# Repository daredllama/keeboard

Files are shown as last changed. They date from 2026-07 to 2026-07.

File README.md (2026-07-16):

# Keeboard



A custom 75%-layout mechanical keyboard, with per-key backlighting, a rotary encoder, a OLED status display, and RMK (Rust) firmware on an RP2040 (Raspberry Pi Pico).

---

## Features

- **79-keys** (78 keys + integrated rotary encoder pushbutton)
- **Per-key backlighting** — SK6812 Mini LEDs, one per switch
- **Rotary encoder** (EC11) — rotation bound to volume, click bound to OLED toggle
- **128×64 I2C OLED** - status display 
- **RMK firmware** (Rust) running on RP2040
- **Sandwich mount** case, plate-mount stabilizers, Cherry MX-compatible switches

---

## Hardware

| Component | Spec |
|---|---|
| MCU | Raspberry Pi Pico (RP2040) |
| Switches | Cherry MX-compatible |
| LEDs | SK6812 Mini, ~79x, per-key |
| Diodes | 1N4148WS (SOD-323) |
| Decoupling caps | 100nF ceramic, 0402 |
| Encoder | EC11 |
| Display | 128×64 I2C OLED (0.96") |
| Stabilizers | Cherry-style plate-mount — 2u (Backspace, Enter, LShift), 6.25u (Spacebar) |

## Plate / Case

- Case screws: M3



## Pin Mapping (RP2040 / Pico)

| Function | GPIO |
|---|---|
| Columns (col0–col14) | GPIO0, 9, 7, 12, 13, 3, 14, 20, 17, 6, 16, 5, 4, 2, 21 |
| Rows (row0–row5) | GPIO15, 11, 10, 8, 1, 22 |
| Encoder A / B | GPIO18 / GPIO19 |
| LED data | GPIO26 |
| OLED SDA / SCL | GPIO27 / GPIO28 |











## Firmware

**Flashing:**
1. Hold the Pico's BOOTSEL button while plugging it in via USB
2. `cargo run --release`
   (uses `elf2uf2-rs` by default — install once with `cargo install elf2uf2-rs`)

**Keymap:** defined in `keyboard.toml` under `[layout].keymap`. 3 layers:
- **Layer 0** — base QWERTY layout matching the F75 layout
- **Layer 1** — Fn layer, RGB controls (mode/brightness on arrow keys)
- **Layer 2** — reserved

## PCB / Assembly Notes

- LEDs are intended to be **reverse-mounted** (bottom side, shining through a PCB cutout) — assembled and soldered by hand, **not** included in the JLCPCB assembly BOM/CPL

## Reflection

For this build, I really challenged myself with tedious ahh work. Even though that making this board was quite tedious, it was a good learning experience,
espcially since this is my first-ever keyboard. I wanted to add a OLED screen so that I could have cool animations or somthing moving on the keyboard while 
I typed. I learned many things form this project, such as how tedious it is to put per-key LEDS for every key. That might have been a mistake. But, I also
learned how to edit/make footprints.

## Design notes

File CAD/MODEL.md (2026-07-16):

## To view the Onshape Doc of this project:

[https://cad.onshape.com/documents/a453df504ee4fbe3ddf03851/w/f0b62b2b0d6551e8bc1848da/e/73e8cfd1b225c73540e4d9f0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](url)

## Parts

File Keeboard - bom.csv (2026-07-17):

Part | Link | Quantity | Cost | Notes
Raspberry Pi Pico | https://www.mouser.com/en/ProductDetail/Raspberry-Pi/SC0915?qs=T%252BzbugeAwjgnLi4azxXVFA%3D%3D&mgh=1 | 1 | $4
0402 100nF Cap | https://jlcpcb.com/partdetail/1877-CL05B104KO5NNNC/C1525 | 79 |  | 0.42 (With PCB)
SOD 323 1n4148 | https://jlcpcb.com/partdetail/2485-1N4148WS/C2128 | 79 |  | 1.08 (With PCB)
0.96" OLED Screen | https://www.aliexpress.us/item/3256805954920554.html?curPageLogUid=JNbJdGII2aV6 | 1 | $0.99
SK6812 MINI-E LED | https://www.lcsc.com/product-detail/C5149201.html?s_z=n_SK6812%2520MINI-E | 79 |  | 5.55 (With PCB)
0402 500 Resistor | https://jlcpcb.com/partdetail/YAGEO-RT0402FRE07500RL/C6460545 | 1 |  | 0.01 (With PCB)
MX 2u Stab | https://www.aliexpress.us/item/2251832678467969.html?src=google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 | 3 | $2.97
MX 6.25u Stab | https://www.aliexpress.us/item/2251832678467969.html?src=google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 | 1 | $0.99
Cherry MX Switch | https://www.aliexpress.us/item/3256802192387196.html?gatewayAdapt=glo2usa4itemAdapt | 78 | $11.53
EC_11 Rotary Encoder (Plum 15mm) | https://jlcpcb.com/parts/componentSearch?searchTxt=ec11%20rotary%20encoder | 1 | $2.12
DSA Keycap 1u | https://www.aliexpress.us/item/3256812054128259.html?src=google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 | 67 | $13.20 | All keycaps in set
DSA Keycap 1.25u |  | 3
DSA Keycap 1.5u |  | 2
DSA Keycap 1.75u |  | 2
DSA Keycap 2u |  | 1
DSA Keycap 2.25 u |  | 2
DSA Keycap 6.25u |  | 1
PCB |  | 2 assembled +3 blank | $82.26
 |  | Total | $118

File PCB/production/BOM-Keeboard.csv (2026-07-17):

Comment | Designator | Footprint | LCSC | Quantity
100nF | C1,C10,C11,C12,C13,C14,C15,C16,C17,C18,C19,C2,C20,C21,C22,C23,C24,C25,C26,C27,C28,C29,C3,C30,C31,C32,C33,C34,C35,C36,C37,C38,C39,C4,C40,C41,C42,C43,C44,C45,C46,C47,C48,C49,C5,C50,C51,C52,C53,C54,C55,C56,C57,C58,C59,C6,C60,C61,C62,C63,C64,C65,C66,C67,C68,C69,C7,C70,C71,C72,C73,C74,C75,C76,C77,C78,C79,C8,C9 | C_0402_1005Metric | C1525 | 79
500 | R1 | R_0402_1005Metric | C6460545 | 1
Diode | D1,D10,D11,D12,D13,D14,D15,D16,D17,D18,D19,D2,D20,D21,D22,D23,D24,D25,D26,D27,D28,D29,D3,D30,D31,D32,D33,D34,D35,D36,D37,D38,D39,D4,D40,D41,D42,D43,D44,D45,D46,D47,D48,D49,D5,D50,D51,D52,D53,D54,D55,D56,D57,D58,D59,D6,D60,D61,D62,D63,D64,D65,D66,D67,D68,D69,D7,D70,D71,D72,D73,D74,D75,D76,D77,D78,D79,D8,D9 | D_SOD-323 | C2128 | 79
SK6812MINI | LED1,LED10,LED11,LED12,LED13,LED14,LED15,LED16,LED17,LED18,LED19,LED2,LED20,LED21,LED22,LED23,LED24,LED25,LED26,LED27,LED28,LED29,LED3,LED30,LED31,LED32,LED33,LED34,LED35,LED36,LED37,LED38,LED39,LED4,LED40,LED41,LED42,LED43,LED44,LED45,LED46,LED47,LED48,LED49,LED5,LED50,LED51,LED52,LED53,LED54,LED55,LED56,LED57,LED58,LED59,LED6,LED60,LED61,LED62,LED63,LED64,LED65,LED66,LED67,LED68,LED69,LED7,LED70,LED71,LED72,LED73,LED74,LED75,LED76,LED77,LED78,LED79,LED8,LED9 | LED_SK6812MINI_PLCC4_3.5x3.5mm_Correct | C5149201 | 79

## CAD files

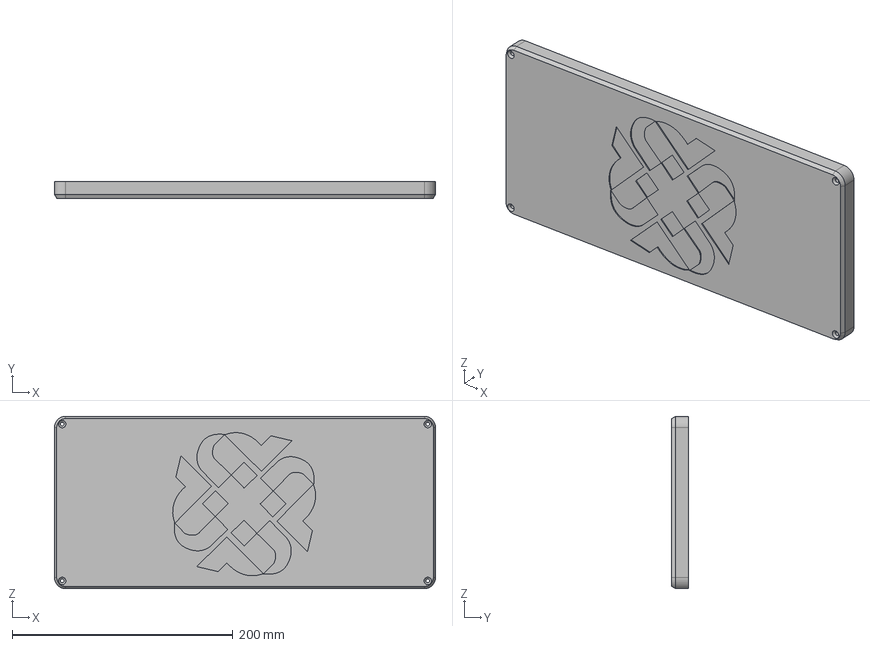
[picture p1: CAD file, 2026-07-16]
CAD/case bottom.step
345.0 x 15.0 x 156.0 mm

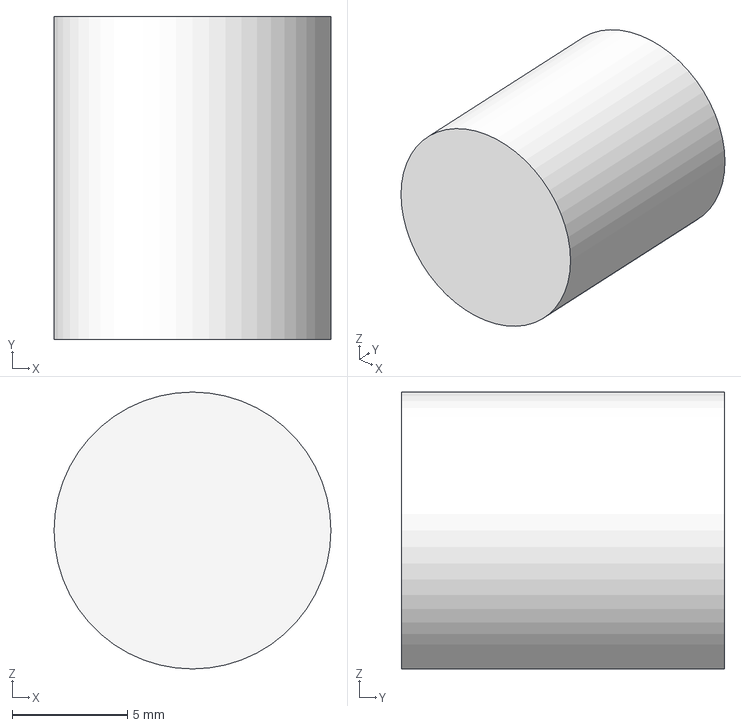
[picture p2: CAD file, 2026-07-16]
CAD/knob.step
12.0 x 14.0 x 12.0 mm

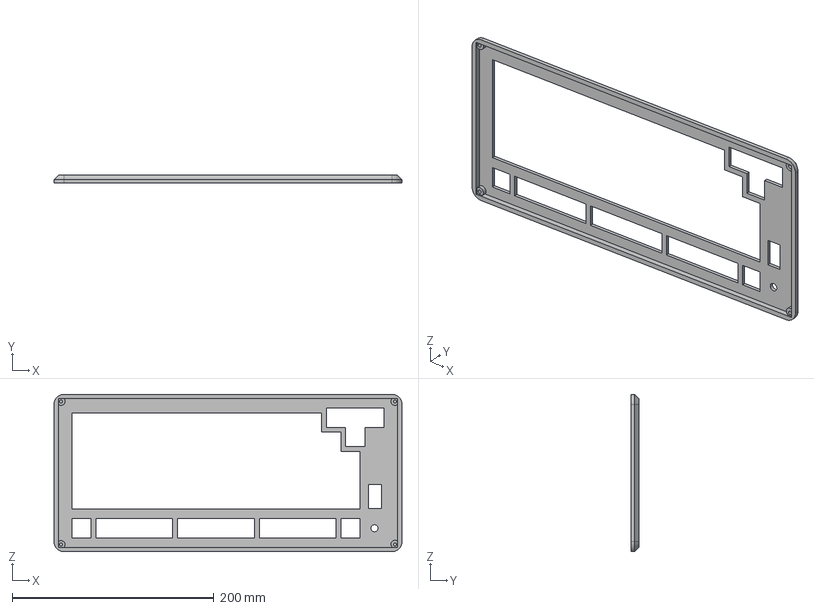
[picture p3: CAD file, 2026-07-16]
CAD/plate.step
345.0 x 8.00 x 156.0 mm

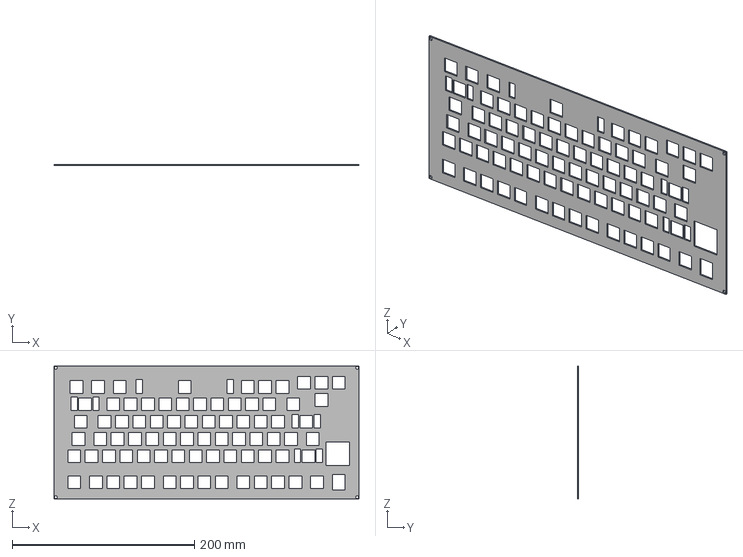
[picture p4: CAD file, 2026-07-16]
CAD/case top.step
335.0 x 1.50 x 146.0 mm

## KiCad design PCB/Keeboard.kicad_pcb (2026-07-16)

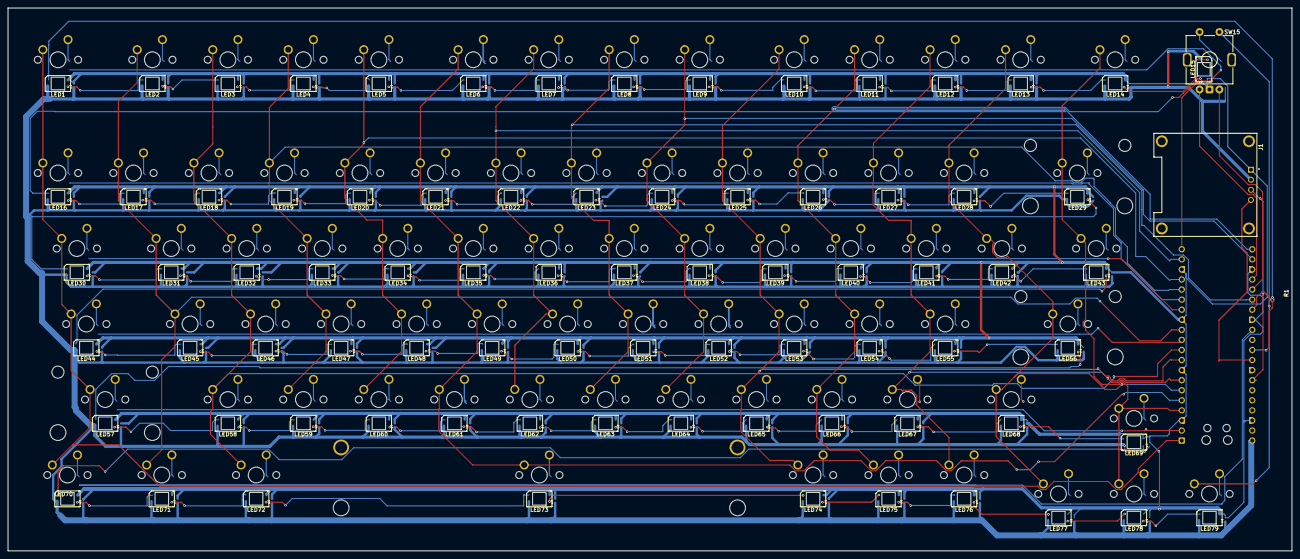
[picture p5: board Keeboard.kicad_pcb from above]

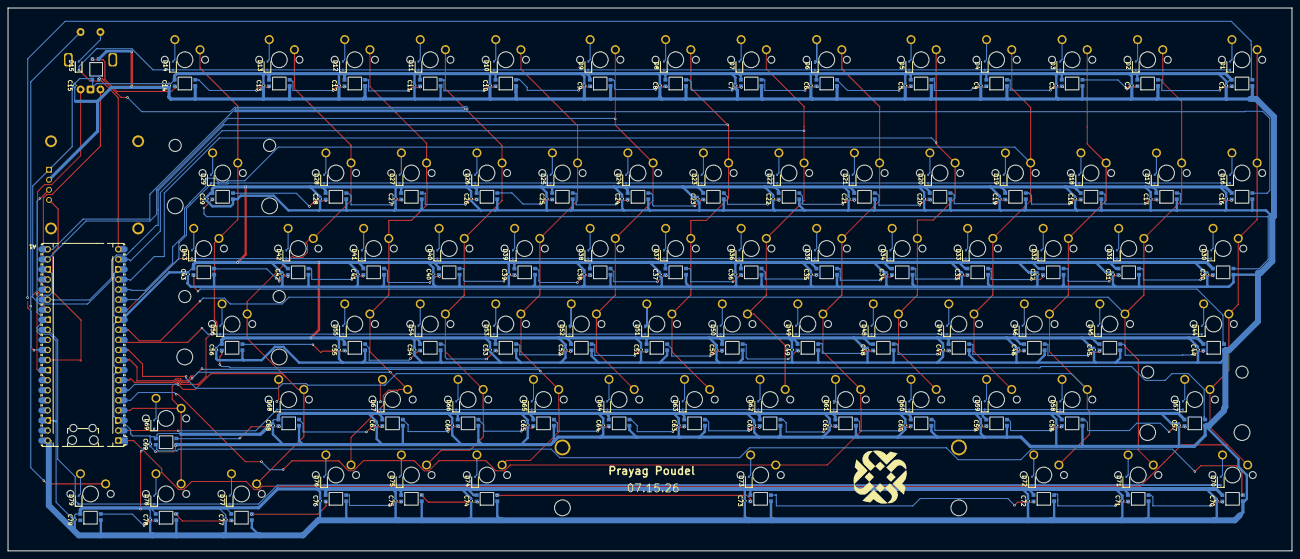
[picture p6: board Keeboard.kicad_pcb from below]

Board: 2 copper layers, 323.9 x 136.9 mm, 323 parts (159 on the bottom side), 186 nets.

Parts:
A1: RaspberryPi_Pico; RaspberryPi_Pico_Common_Unspecified
C1, C2, C3, C4, C5, C6, C7, C8, C9, C10, C11, C12, C13, C14, C15, C16, C17, C18, C19, C20, C21, C22, C23, C24, C25, C26, C27, C28, C29, C30, C31, C32, C33, C34, C35, C36, C37, C38, C39, C40, C41, C42, C43, C44, C45, C46, C47, C48, C49, C50, C51, C52, C53, C54, C55, C56, C57, C58, C59, C60, C61, C62, C63, C64, C65, C66, C67, C68, C69, C70, C71, C72, C73, C74, C75, C76, C77, C78, C79: 100nF; C_0402_1005Metric
D1, D2, D3, D4, D5, D6, D7, D8, D9, D10, D11, D12, D13, D14, D15, D16, D17, D18, D19, D20, D21, D22, D23, D24, D25, D26, D27, D28, D29, D30, D31, D32, D33, D34, D35, D36, D37, D38, D39, D40, D41, D42, D43, D44, D45, D46, D47, D48, D49, D50, D51, D52, D53, D54, D55, D56, D57, D58, D59, D60, D61, D62, D63, D64, D65, D66, D67, D68, D69, D70, D71, D72, D73, D74, D75, D76, D77, D78, D79: Diode; D_SOD-323
J1: OLED; MODULE_DM-OLED096-636
LED1, LED2, LED3, LED4, LED5, LED6, LED7, LED8, LED9, LED10, LED11, LED12, LED13, LED14, LED15, LED16, LED17, LED18, LED19, LED20, LED21, LED22, LED23, LED24, LED25, LED26, LED27, LED28, LED29, LED30, LED31, LED32, LED33, LED34, LED35, LED36, LED37, LED38, LED39, LED40, LED41, LED42, LED43, LED44, LED45, LED46, LED47, LED48, LED49, LED50, LED51, LED52, LED53, LED54, LED55, LED56, LED57, LED58, LED59, LED60, LED61, LED62, LED63, LED64, LED65, LED66, LED67, LED68, LED69, LED70, LED71, LED72, LED73, LED74, LED75, LED76, LED77, LED78, LED79: SK6812MINI; LED_SK6812MINI_PLCC4_3.5x3.5mm_P1.75mm_1
R1: 500; R_0402_1005Metric
ST29: MX_stab; STAB_MX_2u
ST56, ST57: MX_stab; STAB_MX_2.25u
ST73: MX_stab; STAB_MX_P_6.25u
SW1, SW2, SW3, SW4, SW5, SW6, SW7, SW8, SW9, SW10, SW11, SW12, SW13, SW14, SW16, SW17, SW18, SW19, SW20, SW21, SW22, SW23, SW24, SW25, SW26, SW27, SW28, SW29, SW31, SW32, SW33, SW34, SW35, SW36, SW37, SW38, SW39, SW40, SW41, SW42, SW45, SW46, SW47, SW48, SW49, SW50, SW51, SW52, SW53, SW54, SW55, SW56, SW57, SW58, SW59, SW60, SW61, SW62, SW63, SW64, SW65, SW66, SW67, SW69, SW73, SW74, SW75, SW76, SW77, SW78, SW79: SW_MX_1u
SW15: Rotary; ROT_Alps_EC11E-Switch
SW30, SW43: SW_MX_1.5u
SW44, SW68: SW_MX_1.75u
SW70, SW71, SW72: SW_MX_1.25u

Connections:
+5V: A1.40 (VBUS), C1.1, C2.1, C3.1, C4.1, C5.1, C6.1, C7.1, C8.1, C9.1, C10.1, C11.1, C12.1, C13.1, C14.1, C15.1, C16.1, C17.1, C18.1, C19.1, C20.1, C21.1, C22.1, C23.1, C24.1, C25.1, C26.1, C27.1, C28.1, C29.1, C30.1, C31.1, C32.1, C33.1, C34.1, C35.1, C36.1, C37.1, C38.1, C39.1, C40.1, C41.1, C42.1, C43.1, C44.1, C45.1, C46.1, C47.1, C48.1, C49.1, C50.1, C51.1, C52.1, C53.1, C54.1, C55.1, C56.1, C57.1, C58.1, C59.1, C60.1, C61.1, C62.1, C63.1, C64.1, C65.1, C66.1, C67.1, C68.1, C69.1, C70.1, C71.1, C72.1, C73.1, C74.1, C75.1, C76.1, C77.1, C78.1, C79.1, J1.2, LED1.4 (VDD), LED2.4 (VDD), LED3.4 (VDD), LED4.4 (VDD), LED5.4 (VDD), LED6.4 (VDD), LED7.4 (VDD), LED8.4 (VDD), LED9.4 (VDD), LED10.4 (VDD), LED11.4 (VDD), LED12.4 (VDD), LED13.4 (VDD), LED14.4 (VDD), LED15.4 (VDD), LED16.4 (VDD), LED17.4 (VDD), LED18.4 (VDD), LED19.4 (VDD), LED20.4 (VDD), LED21.4 (VDD), LED22.4 (VDD), LED23.4 (VDD), LED24.4 (VDD), LED25.4 (VDD), LED26.4 (VDD), LED27.4 (VDD), LED28.4 (VDD), LED29.4 (VDD), LED30.4 (VDD), LED31.4 (VDD), LED32.4 (VDD), LED33.4 (VDD), LED34.4 (VDD), LED35.4 (VDD), LED36.4 (VDD), LED37.4 (VDD), LED38.4 (VDD), LED39.4 (VDD), LED40.4 (VDD), LED41.4 (VDD), LED42.4 (VDD), LED43.4 (VDD), LED44.4 (VDD), LED45.4 (VDD), LED46.4 (VDD), LED47.4 (VDD), LED48.4 (VDD), LED49.4 (VDD), LED50.4 (VDD), LED51.4 (VDD), LED52.4 (VDD), LED53.4 (VDD), LED54.4 (VDD), LED55.4 (VDD), LED56.4 (VDD), LED57.4 (VDD), LED58.4 (VDD), LED59.4 (VDD), LED60.4 (VDD), LED61.4 (VDD), LED62.4 (VDD), LED63.4 (VDD), LED64.4 (VDD), LED65.4 (VDD), LED66.4 (VDD), LED67.4 (VDD), LED68.4 (VDD), LED69.4 (VDD), LED70.4 (VDD), LED71.4 (VDD), LED72.4 (VDD), LED73.4 (VDD), LED74.4 (VDD), LED75.4 (VDD), LED76.4 (VDD), LED77.4 (VDD), LED78.4 (VDD), LED79.4 (VDD)
GND: A1.3 (GND), A1.8 (GND), A1.13 (GND), A1.18 (GND), A1.23 (GND), A1.28 (GND), A1.38 (GND), C1.2, C2.2, C3.2, C4.2, C5.2, C6.2, C7.2, C8.2, C9.2, C10.2, C11.2, C12.2, C13.2, C14.2, C15.2, C16.2, C17.2, C18.2, C19.2, C20.2, C21.2, C22.2, C23.2, C24.2, C25.2, C26.2, C27.2, C28.2, C29.2, C30.2, C31.2, C32.2, C33.2, C34.2, C35.2, C36.2, C37.2, C38.2, C39.2, C40.2, C41.2, C42.2, C43.2, C44.2, C45.2, C46.2, C47.2, C48.2, C49.2, C50.2, C51.2, C52.2, C53.2, C54.2, C55.2, C56.2, C57.2, C58.2, C59.2, C60.2, C61.2, C62.2, C63.2, C64.2, C65.2, C66.2, C67.2, C68.2, C69.2, C70.2, C71.2, C72.2, C73.2, C74.2, C75.2, C76.2, C77.2, C78.2, C79.2, J1.1, LED1.2 (VSS), LED2.2 (VSS), LED3.2 (VSS), LED4.2 (VSS), LED5.2 (VSS), LED6.2 (VSS), LED7.2 (VSS), LED8.2 (VSS), LED9.2 (VSS), LED10.2 (VSS), LED11.2 (VSS), LED12.2 (VSS), LED13.2 (VSS), LED14.2 (VSS), LED15.2 (VSS), LED16.2 (VSS), LED17.2 (VSS), LED18.2 (VSS), LED19.2 (VSS), LED20.2 (VSS), LED21.2 (VSS), LED22.2 (VSS), LED23.2 (VSS), LED24.2 (VSS), LED25.2 (VSS), LED26.2 (VSS), LED27.2 (VSS), LED28.2 (VSS), LED29.2 (VSS), LED30.2 (VSS), LED31.2 (VSS), LED32.2 (VSS), LED33.2 (VSS), LED34.2 (VSS), LED35.2 (VSS), LED36.2 (VSS), LED37.2 (VSS), LED38.2 (VSS), LED39.2 (VSS), LED40.2 (VSS), LED41.2 (VSS), LED42.2 (VSS), LED43.2 (VSS), LED44.2 (VSS), LED45.2 (VSS), LED46.2 (VSS), LED47.2 (VSS), LED48.2 (VSS), LED49.2 (VSS), LED50.2 (VSS), LED51.2 (VSS), LED52.2 (VSS), LED53.2 (VSS), LED54.2 (VSS), LED55.2 (VSS), LED56.2 (VSS), LED57.2 (VSS), LED58.2 (VSS), LED59.2 (VSS), LED60.2 (VSS), LED61.2 (VSS), LED62.2 (VSS), LED63.2 (VSS), LED64.2 (VSS), LED65.2 (VSS), LED66.2 (VSS), LED67.2 (VSS), LED68.2 (VSS), LED69.2 (VSS), LED70.2 (VSS), LED71.2 (VSS), LED72.2 (VSS), LED73.2 (VSS), LED74.2 (VSS), LED75.2 (VSS), LED76.2 (VSS), LED77.2 (VSS), LED78.2 (VSS), LED79.2 (VSS), SW15.C
LED: A1.31 (GPIO26_ADC0), R1.2
unnamed: D1.2 (A), SW1.2
unnamed: D2.2 (A), SW2.2
unnamed: D3.2 (A), SW3.2
unnamed: D4.2 (A), SW4.2
unnamed: D5.2 (A), SW5.2
unnamed: D6.2 (A), SW6.2
unnamed: D7.2 (A), SW7.2
unnamed: D8.2 (A), SW8.2
unnamed: D9.2 (A), SW9.2
unnamed: D10.2 (A), SW10.2
unnamed: D11.2 (A), SW11.2
unnamed: D12.2 (A), SW12.2
unnamed: D13.2 (A), SW13.2
unnamed: D14.2 (A), SW14.2
unnamed: D16.2 (A), SW16.2
unnamed: D17.2 (A), SW17.2
unnamed: D18.2 (A), SW18.2
unnamed: D19.2 (A), SW19.2
unnamed: D20.2 (A), SW20.2
unnamed: D21.2 (A), SW21.2
unnamed: D22.2 (A), SW22.2
unnamed: D23.2 (A), SW23.2
unnamed: D24.2 (A), SW24.2
unnamed: D25.2 (A), SW25.2
unnamed: D26.2 (A), SW26.2
unnamed: D27.2 (A), SW27.2
unnamed: D28.2 (A), SW28.2
unnamed: D29.2 (A), SW29.2
unnamed: D30.2 (A), SW30.2
unnamed: D31.2 (A), SW31.2
unnamed: D32.2 (A), SW32.2
unnamed: D33.2 (A), SW33.2
unnamed: D34.2 (A), SW34.2
unnamed: D35.2 (A), SW35.2
unnamed: D36.2 (A), SW36.2
unnamed: D37.2 (A), SW37.2
unnamed: D38.2 (A), SW38.2
unnamed: D39.2 (A), SW39.2
unnamed: D40.2 (A), SW40.2
unnamed: D41.2 (A), SW41.2
unnamed: D42.2 (A), SW42.2
unnamed: D43.2 (A), SW43.2
unnamed: D44.2 (A), SW44.2
unnamed: D45.2 (A), SW45.2
unnamed: D46.2 (A), SW46.2
unnamed: D47.2 (A), SW47.2
unnamed: D48.2 (A), SW48.2
unnamed: D49.2 (A), SW49.2
unnamed: D50.2 (A), SW50.2
unnamed: D51.2 (A), SW51.2
unnamed: D52.2 (A), SW52.2
unnamed: D53.2 (A), SW53.2
unnamed: D54.2 (A), SW54.2
unnamed: D55.2 (A), SW55.2
unnamed: D56.2 (A), SW56.2
unnamed: D57.2 (A), SW57.2
unnamed: D58.2 (A), SW58.2
unnamed: D59.2 (A), SW59.2
unnamed: D60.2 (A), SW60.2
unnamed: D61.2 (A), SW61.2
unnamed: D62.2 (A), SW62.2
unnamed: D63.2 (A), SW63.2
unnamed: D64.2 (A), SW64.2
unnamed: D65.2 (A), SW65.2
unnamed: D66.2 (A), SW66.2
unnamed: D67.2 (A), SW67.2
unnamed: D68.2 (A), SW68.2
unnamed: D69.2 (A), SW69.2
unnamed: D70.2 (A), SW70.2
unnamed: D71.2 (A), SW71.2
unnamed: D72.2 (A), SW72.2
unnamed: D73.2 (A), SW73.2
unnamed: D74.2 (A), SW74.2
unnamed: D75.2 (A), SW75.2
unnamed: D76.2 (A), SW76.2
unnamed: D77.2 (A), SW77.2
unnamed: D78.2 (A), SW78.2
unnamed: D79.2 (A), SW79.2
unnamed: LED1.3 (DIN), R1.1
unnamed: LED1.1 (DOUT), LED2.3 (DIN)
unnamed: LED2.1 (DOUT), LED3.3 (DIN)
unnamed: LED3.1 (DOUT), LED4.3 (DIN)
unnamed: LED4.1 (DOUT), LED5.3 (DIN)
unnamed: LED5.1 (DOUT), LED6.3 (DIN)
unnamed: LED6.1 (DOUT), LED7.3 (DIN)
unnamed: LED7.1 (DOUT), LED8.3 (DIN)
unnamed: LED8.1 (DOUT), LED9.3 (DIN)
unnamed: LED9.1 (DOUT), LED10.3 (DIN)
unnamed: LED10.1 (DOUT), LED11.3 (DIN)
unnamed: LED11.1 (DOUT), LED12.3 (DIN)
unnamed: LED12.1 (DOUT), LED13.3 (DIN)
unnamed: LED13.1 (DOUT), LED14.3 (DIN)
unnamed: LED14.1 (DOUT), LED15.3 (DIN)
unnamed: LED15.1 (DOUT), LED16.3 (DIN)
unnamed: LED16.1 (DOUT), LED17.3 (DIN)
unnamed: LED17.1 (DOUT), LED18.3 (DIN)
unnamed: LED18.1 (DOUT), LED19.3 (DIN)
unnamed: LED19.1 (DOUT), LED20.3 (DIN)
unnamed: LED20.1 (DOUT), LED21.3 (DIN)
unnamed: LED21.1 (DOUT), LED22.3 (DIN)
unnamed: LED22.1 (DOUT), LED23.3 (DIN)
unnamed: LED23.1 (DOUT), LED24.3 (DIN)
unnamed: LED24.1 (DOUT), LED25.3 (DIN)
unnamed: LED25.1 (DOUT), LED26.3 (DIN)
unnamed: LED26.1 (DOUT), LED27.3 (DIN)
unnamed: LED27.1 (DOUT), LED28.3 (DIN)
unnamed: LED28.1 (DOUT), LED29.3 (DIN)
unnamed: LED29.1 (DOUT), LED30.3 (DIN)
unnamed: LED30.1 (DOUT), LED31.3 (DIN)
unnamed: LED31.1 (DOUT), LED32.3 (DIN)
unnamed: LED32.1 (DOUT), LED33.3 (DIN)
unnamed: LED33.1 (DOUT), LED34.3 (DIN)
unnamed: LED34.1 (DOUT), LED35.3 (DIN)
unnamed: LED35.1 (DOUT), LED36.3 (DIN)
unnamed: LED36.1 (DOUT), LED37.3 (DIN)
unnamed: LED37.1 (DOUT), LED38.3 (DIN)
unnamed: LED38.1 (DOUT), LED39.3 (DIN)
unnamed: LED39.1 (DOUT), LED40.3 (DIN)
unnamed: LED40.1 (DOUT), LED41.3 (DIN)
unnamed: LED41.1 (DOUT), LED42.3 (DIN)
unnamed: LED42.1 (DOUT), LED43.3 (DIN)
unnamed: LED43.1 (DOUT), LED44.3 (DIN)
unnamed: LED44.1 (DOUT), LED45.3 (DIN)
unnamed: LED45.1 (DOUT), LED46.3 (DIN)
unnamed: LED46.1 (DOUT), LED47.3 (DIN)
unnamed: LED47.1 (DOUT), LED48.3 (DIN)
unnamed: LED48.1 (DOUT), LED49.3 (DIN)
unnamed: LED49.1 (DOUT), LED50.3 (DIN)
unnamed: LED50.1 (DOUT), LED51.3 (DIN)
unnamed: LED51.1 (DOUT), LED52.3 (DIN)
unnamed: LED52.1 (DOUT), LED53.3 (DIN)
unnamed: LED53.1 (DOUT), LED54.3 (DIN)
unnamed: LED54.1 (DOUT), LED55.3 (DIN)
unnamed: LED55.1 (DOUT), LED56.3 (DIN)
unnamed: LED56.1 (DOUT), LED57.3 (DIN)
unnamed: LED57.1 (DOUT), LED58.3 (DIN)
unnamed: LED58.1 (DOUT), LED59.3 (DIN)
unnamed: LED59.1 (DOUT), LED60.3 (DIN)
unnamed: LED60.1 (DOUT), LED61.3 (DIN)
unnamed: LED61.1 (DOUT), LED62.3 (DIN)
unnamed: LED62.1 (DOUT), LED63.3 (DIN)
unnamed: LED63.1 (DOUT), LED64.3 (DIN)
unnamed: LED64.1 (DOUT), LED65.3 (DIN)
unnamed: LED65.1 (DOUT), LED66.3 (DIN)
unnamed: LED66.1 (DOUT), LED67.3 (DIN)
unnamed: LED67.1 (DOUT), LED68.3 (DIN)
unnamed: LED68.1 (DOUT), LED69.3 (DIN)
unnamed: LED69.1 (DOUT), LED70.3 (DIN)
unnamed: LED70.1 (DOUT), LED71.3 (DIN)
unnamed: LED71.1 (DOUT), LED72.3 (DIN)
unnamed: LED72.1 (DOUT), LED73.3 (DIN)
unnamed: LED73.1 (DOUT), LED74.3 (DIN)
unnamed: LED74.1 (DOUT), LED75.3 (DIN)
unnamed: LED75.1 (DOUT), LED76.3 (DIN)
unnamed: LED76.1 (DOUT), LED77.3 (DIN)
unnamed: LED77.1 (DOUT), LED78.3 (DIN)
unnamed: LED78.1 (DOUT), LED79.3 (DIN)
RotA: A1.24 (GPIO18), SW15.A
RotB: A1.25 (GPIO19), SW15.B
RotS1: A1.27 (GPIO21), SW15.S1, SW79.1
RotS2: D15.2 (A), SW15.S2
SCL: A1.34 (GPIO28_ADC2), J1.3
SDA: A1.32 (GPIO27_ADC1), J1.4
col0: A1.1 (GPIO0), SW1.1, SW16.1, SW30.1, SW44.1, SW57.1, SW70.1
col1: A1.12 (GPIO9), SW2.1, SW17.1, SW31.1, SW45.1, SW71.1
col2: A1.10 (GPIO7), SW3.1, SW18.1, SW32.1, SW46.1, SW58.1, SW72.1
col3: A1.16 (GPIO12), SW4.1, SW19.1, SW33.1, SW47.1, SW59.1
col4: A1.17 (GPIO13), SW5.1, SW20.1, SW34.1, SW48.1, SW60.1
col5: A1.5 (GPIO3), SW6.1, SW21.1, SW35.1, SW49.1, SW61.1, SW73.1
col6: A1.19 (GPIO14), SW7.1, SW22.1, SW36.1, SW50.1, SW62.1
col7: A1.26 (GPIO20), SW8.1, SW23.1, SW37.1, SW51.1, SW63.1
col8: A1.22 (GPIO17), SW9.1, SW24.1, SW38.1, SW52.1, SW64.1
col9: A1.9 (GPIO6), SW10.1, SW25.1, SW39.1, SW53.1, SW65.1, SW74.1
col10: A1.21 (GPIO16), SW11.1, SW26.1, SW40.1, SW54.1, SW66.1, SW75.1
col11: A1.7 (GPIO5), SW12.1, SW27.1, SW41.1, SW55.1, SW67.1, SW76.1
col12: A1.6 (GPIO4), SW13.1, SW28.1, SW42.1, SW56.1, SW68.1, SW77.1
col13: A1.4 (GPIO2), SW14.1, SW29.1, SW43.1, SW69.1, SW78.1
row0: A1.20 (GPIO15), D1.1 (K), D2.1 (K), D3.1 (K), D4.1 (K), D5.1 (K), D6.1 (K), D7.1 (K), D8.1 (K), D9.1 (K), D10.1 (K), D11.1 (K), D12.1 (K), D13.1 (K), D14.1 (K), D15.1 (K)
row1: A1.15 (GPIO11), D16.1 (K), D17.1 (K), D18.1 (K), D19.1 (K), D20.1 (K), D21.1 (K), D22.1 (K), D23.1 (K), D24.1 (K), D25.1 (K), D26.1 (K), D27.1 (K), D28.1 (K), D29.1 (K)
row2: A1.14 (GPIO10), D30.1 (K), D31.1 (K), D32.1 (K), D33.1 (K), D34.1 (K), D35.1 (K), D36.1 (K), D37.1 (K), D38.1 (K), D39.1 (K), D40.1 (K), D41.1 (K), D42.1 (K), D43.1 (K)
row3: A1.11 (GPIO8), D44.1 (K), D45.1 (K), D46.1 (K), D47.1 (K), D48.1 (K), D49.1 (K), D50.1 (K), D51.1 (K), D52.1 (K), D53.1 (K), D54.1 (K), D55.1 (K), D56.1 (K)
row4: A1.2 (GPIO1), D57.1 (K), D58.1 (K), D59.1 (K), D60.1 (K), D61.1 (K), D62.1 (K), D63.1 (K), D64.1 (K), D65.1 (K), D66.1 (K), D67.1 (K), D68.1 (K), D69.1 (K)
row5: A1.29 (GPIO22), D70.1 (K), D71.1 (K), D72.1 (K), D73.1 (K), D74.1 (K), D75.1 (K), D76.1 (K), D77.1 (K), D78.1 (K), D79.1 (K)

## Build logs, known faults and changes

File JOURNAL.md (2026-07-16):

# Keyboard Build Journal

## Entry 1 — Figuring out hardware and layout
**Date: 7/11/2026**

Started planning out the layout for the keyboard. I really didn't want a bulky keybaord,
but at the same time, I wanted to maintain most of the function that I would have on 
a conventional laptop. So, I settled with a 75% layout, I used the reference picture below.



## Entry 2 — Deciding how to light this thing up
**Date: 7/12/2026**

Went back and forth between per-key RGB, underglow, and a "backlit"
middle-ground option. Landed on full backlit — one LED under every single
switch (~79-84 depending on final key count). I realized the switches
I've got already have that clear/translucent housing built for exactly this. I also realized this was gonna be a tedious task.



## Entry 3 — Building the LED chain in the schematic
**Date: 7/12/2026**

Got the SK6812 schematic block down: VDD/GND, a 100nF decoupling cap per
LED, DIN/DOUT chained through. Added a ~500Ω resistor on just the first
LED's DIN (protects against voltage spikes, only needed once at the start
of the chain). Copy-pasted that pattern like 79 times.



## Entry 4 — Rotary encoder + OLED wiring
**Date: 7/13/2026**

Wired up the EC11 encoder (A/B/C for rotation, S1/S2 for the click).
Spent a while figuring out OLED options — I wanted I looong screen put apparently
4 pin OLEDs don't come in 256x32, so I had to settle for a 128x64 display, which gave
a me a bit more surface area.



## Entry 5 — Locking in the matrix and pin map
**Date: 7/13/2026**

Finalized the switch matrix at 15 columns × 6 rows — 79 switch positions
total, including the encoder's click. Assigned every single GPIO on the
Pico (all 26, no spares left) across the matrix, encoder, LED, and OLED.
Also worked out all the stab sizes and key widths based on the F75 layout
I'm copying.



## Entry 6 — Where do I put LEDs?
**Date: 7/14/2026**

Originally when I made my previous hackpad, I put the LEDS in between the swithes,
which I soon figured out was not viable for this build.
So I solved it by going reverse-mount (LED on the back of the board, shining
through a cutout). Little did I know how tedious wiring all the caps and LEDS was going to be. I quite litereally spent the ENTIRE
day wiring this. Sigh.



## Entry 7 — Plate and case stuff
**Date: 7/14/2026**

Decided to do some CAD (I am most comfortable w/ this). Learned
about the different keyboard mounting styles (tray, top, bottom,
sandwich, gasket, etc.) and went with sandwich mount — simple to design.
I made it very cool and sleek looking.



## Entry 8 — Getting the firmware going (RMK)
**Date: 7/15/2026**

Decided to do this one in RMK instead of QMK since I've already done a QMK
board before (ZePad) and wanted to try something new. Since I'm kinda unfamiliar with this,
I use a lot of placeholders for things I will come to later. Also wrote in the other files.

## Entry 9 — Getting ready for assembly
**Date: 7/15/2026**

Finalized all of the rest of the files which included finding the prices for 
the BOM and also writing the README and JOURNAL.

Total Hours: prolly 20ish.
